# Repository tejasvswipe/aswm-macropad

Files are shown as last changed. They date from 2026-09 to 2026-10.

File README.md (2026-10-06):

# hackpad 
## show rather then tell 
### used xiao  rp2040 , 16 keys ,roatary incoder ,  and some stuff from my  side
hackpad16_backhackpad16_schematic_previewhackpad16_pcb_preview
hackpad16_front
hackpad16_back

[hackpadSCH.pdf](https://github.com/user-attachments/files/33123543/hackpadSCH.pdf)




| Component | What it do | GPIO | Receipts |
| :--- | :--- | :---: | :--- |
| Display Mux | SDA / SCL | `GPIO8` / `GPIO9` | pull-ups are your friends! |
| Neon Lighting | WS2812B Data | `GPIO4` | requires 5V logic shifts |
| The Dial | Encoder A / B / SW | `GPIO5` / `GPIO6` / `GPIO7` | uses quadrature ISR |
| Top Keys | SW1 / SW2 | `GPIO1` / `GPIO2` | crisped debounced |
| Mid Keys | SW3 / SW4 / SW7 | `GPIO42` / `GPIO41` / `GPIO40` | crisped debounced v2 |

| Bot Keys | SW6 / SW8 / SW9 | `GPIO39` / `GPIO38` / `GPIO21` | swap these keys if they do dumb things |
rt tracking your Spotify streams?

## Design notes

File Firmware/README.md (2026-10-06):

# Hackpad firmware

This is CircuitPython firmware for the **actual PCB in this repository**: a Seeed XIAO RP2040, 4×4 diode matrix, and EC11 encoder.

## Install

1. Install CircuitPython for **Seeed XIAO RP2040**.
2. Copy `boot.py` and `code.py` to the board's `CIRCUITPY` drive.
3. Copy the `adafruit_hid` library folder from the CircuitPython bundle to `CIRCUITPY/lib/`.
4. Reconnect USB. The board now appears as a keyboard plus media-control device.

## Keymap

| Key | Action |
|---|---|
| SW1 | Ctrl+C |
| SW2 | Ctrl+V |
| SW3 | Chrome next tab, Ctrl+Tab |
| SW4 | Chrome previous tab, Ctrl+Shift+Tab |
| SW5 | Chrome new tab, Ctrl+T |
| SW6 | Close tab, Ctrl+W |
| SW7 | Focus address bar, Ctrl+L |
| SW8…SW16 | Win+1…Win+9 |
| Encoder clockwise/counter-clockwise | Volume up/down |
| Encoder press | Play/pause media, including Spotify |

If the encoder direction is backwards, swap `ENC_A` and `ENC_B` in `code.py`.

## Important hardware note

The committed PCB does **not** contain the OLED displays, I²C mux, ESP32-S3, or RGB LEDs described in the README text. It is a 4×4 matrix wired to every usable XIAO RP2040 GPIO. Therefore this firmware cannot display the current time on the shipped PCB without a hardware revision that adds an OLED and frees/reroutes I²C pins.

`host/companion.py` is included as an optional time sender for a future display-equipped revision; it is not needed for the keys or encoder.

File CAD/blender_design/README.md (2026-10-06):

# Hackpad 16 — Blender case redesign

A redesigned, two-piece sandwich enclosure for the supplied 100 × 100 mm Hackpad 16 PCB. The case follows the Hackpad guide dimensions and keeps the existing board’s actual asymmetric mounting-hole locations.

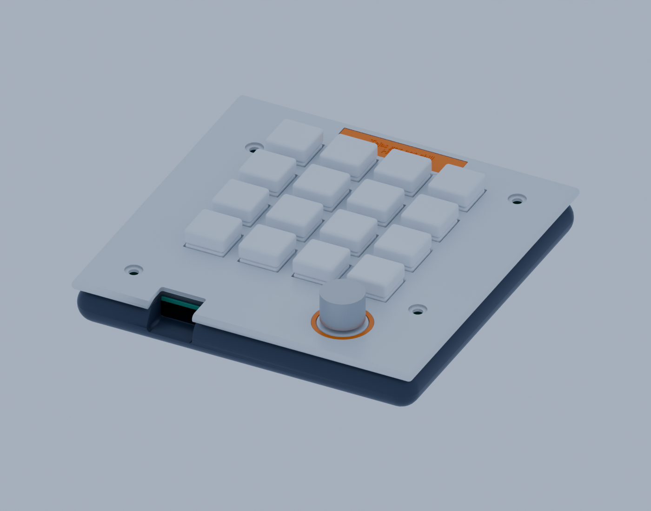
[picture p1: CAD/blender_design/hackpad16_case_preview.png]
Hackpad 16 case preview


## Guide dimensions used

- PCB cavity: 100.4 × 100.4 mm, giving 0.2 mm clearance on each side
- Outer case: 120 × 120 mm, giving a 10 mm border around the PCB
- Lower tray: 3 mm floor and 10 mm side wall
- Top switch plate: 3 mm thick
- Switches: 4 × 4 grid at 19.05 mm pitch, with 14.4 mm plate openings

The case also has an edge opening for USB-C, four PCB-matched standoffs and plate screw holes, a 7.4 mm EC11 bushing opening, a separate accent ring, and an underside hatch for access to the XIAO BOOT/RESET buttons. The badge reads “Tejas got not chill” over “Hackpad.”

The visual encoder knob is narrower than the bezel opening and stands 1.5 mm above the plate at its lower edge, leaving room for the knob to move down when pressed. The electrical click is provided by the EC11 encoder’s integrated push switch on the PCB. The real encoder and selected knob still need a physical press-fit check.

## Files

- hackpad16_case.blend — editable Blender scene. Printable case parts have numbered names; objects labelled PROXY ONLY are visual placeholders and are not printing parts.
- lower_tray.stl — lower case, including PCB standoffs and service opening
- switch_plate.stl — top plate and switch/encoder openings
- service_hatch.stl — removable access cover
- encoder_bezel.stl — optional accent ring with extra clearance around a pressable knob
- hackpad16_badge.stl — separate Tejas got not chill / Hackpad badge
- hackpad16_case_preview.png — assembled render
- build_case.py — Blender script used to generate the model and STLs

The STL files are each positioned on Z=0 for easier slicing. Print the lower tray with its floor on the bed and the plate flat. A sensible first pass is 0.2 mm layers, 3–4 walls, and 20–30% infill.

## Assembly and fit

The board pattern is intentionally asymmetric, so use this exact PCB. Use four M3 screws through the plate and PCB into the tray’s 2.7 mm pilot holes; confirm screw length against your print and board stack. The service hatch uses four M2 self-tapping screws.

This is a CAD redesign and has not been physically test-fitted. Before printing everything, test one switch opening and check the exact switches, encoder nut/bushing, USB-C plug, board standoff alignment, and XIAO service-hatch access against your hardware and printer. Dimensions may need adjustment for printer shrinkage and component tolerances.

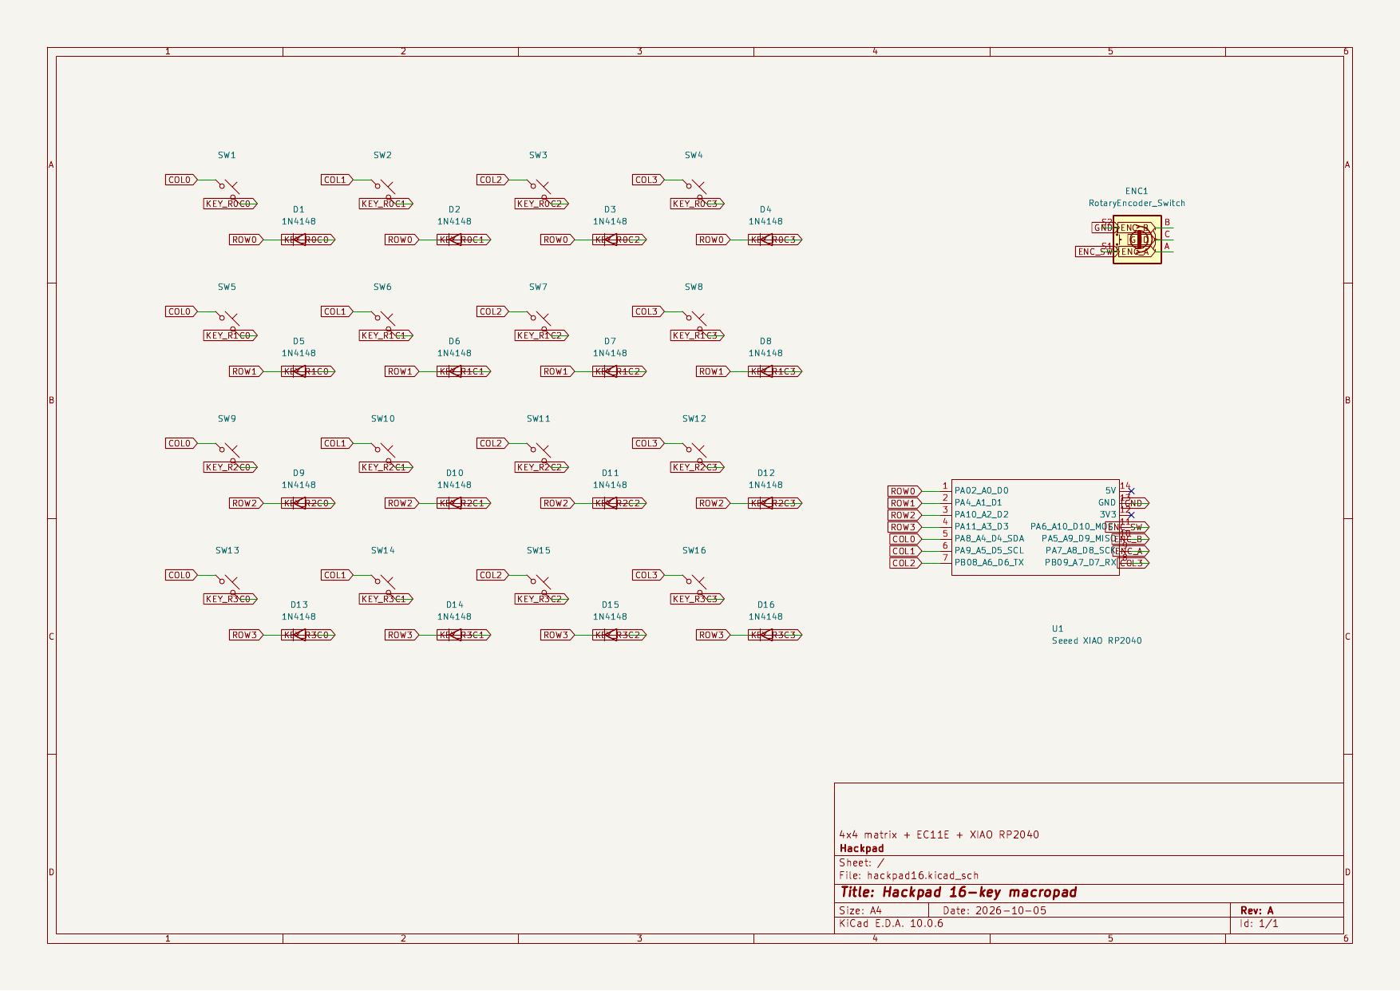
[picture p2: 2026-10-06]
PCB/previews/hackpad16_schematic_preview.png

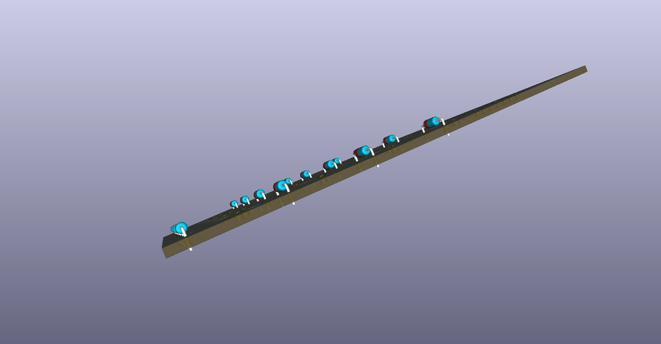
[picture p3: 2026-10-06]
PCB/hackpad16.png

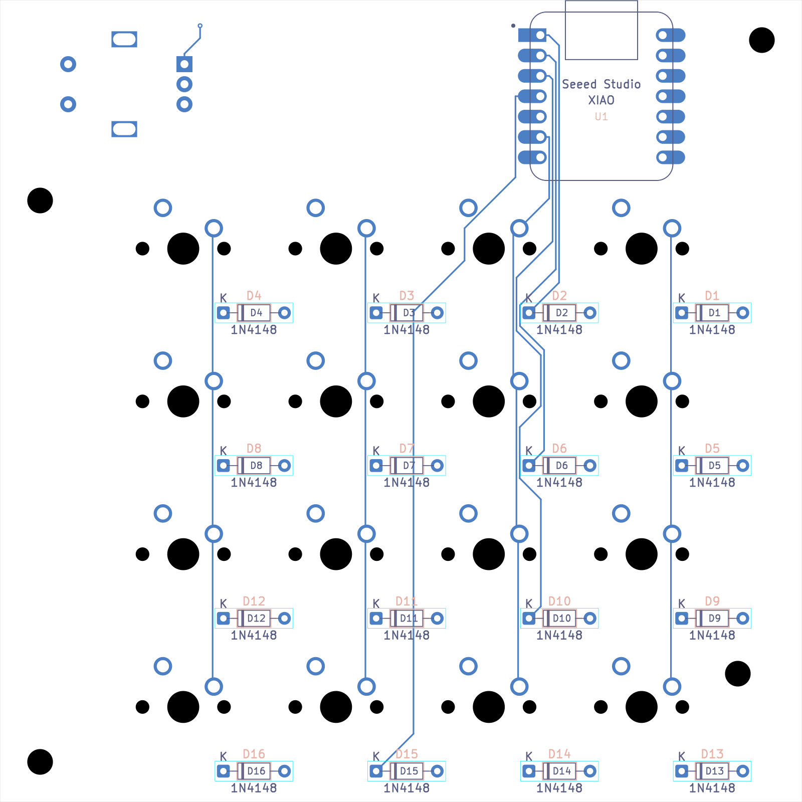
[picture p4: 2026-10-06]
PCB/previews/hackpad16_back.png

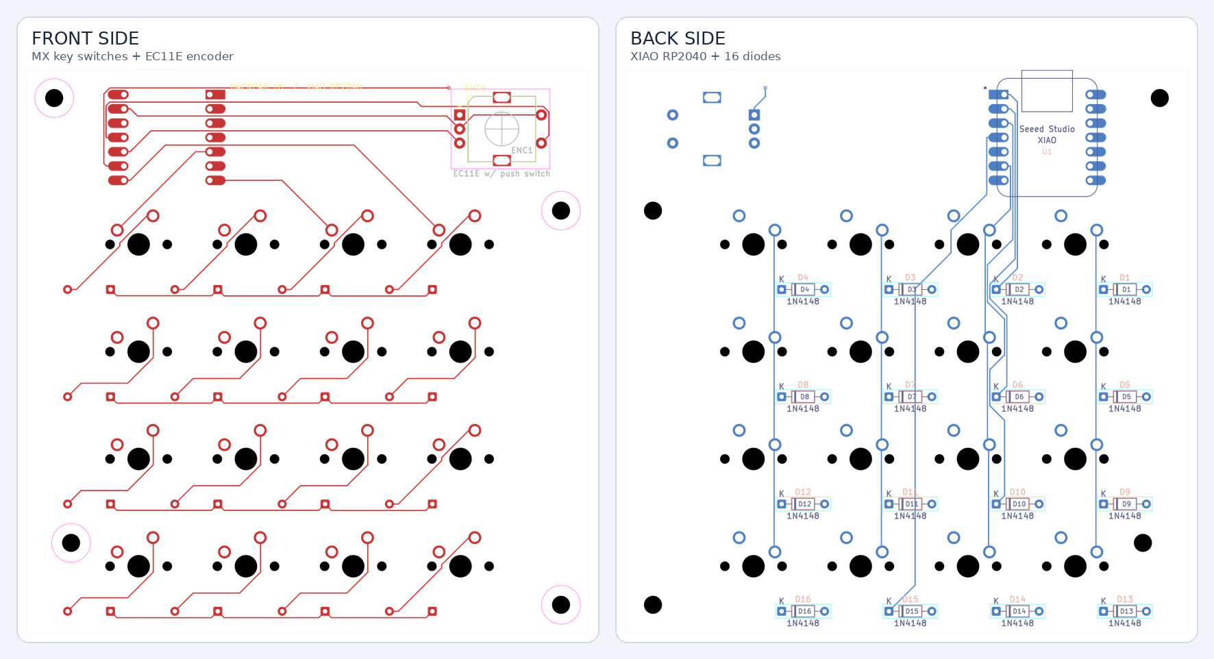
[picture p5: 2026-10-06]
PCB/previews/hackpad16_pcb_preview.png

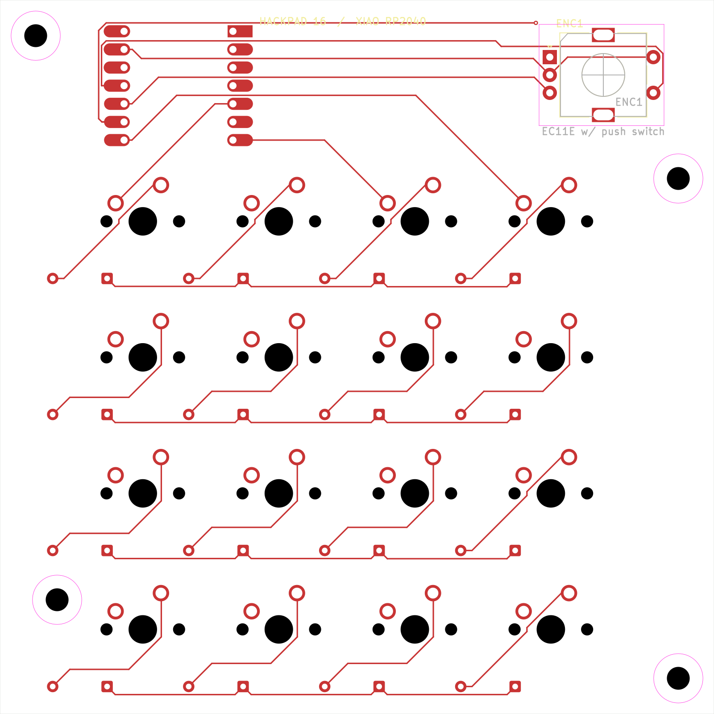
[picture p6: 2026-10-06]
PCB/previews/hackpad16_front.png

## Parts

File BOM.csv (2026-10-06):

Quantity | Part | Specification / notes | Reference link
1 | XIAO RP2040 | Seeed XIAO RP2040 module | https://wiki.seeedstudio.com/XIAO-RP2040/
16 | Mechanical key switch | MX-compatible 1U; select preferred switch | https://www.digikey.in/en/products/result?keywords=MX%20keyboard%20switch
16 | Signal diode | 1N4148 through-hole | https://www.onsemi.com/pdf/datasheet/1n4148-d.pdf
1 | Rotary encoder with push switch | EC11E-compatible; verify shaft and bushing variant | https://www.digikey.in/en/products/result?keywords=EC11E%20encoder
16 | Keycap | MX-compatible 1U | https://www.digikey.in/en/products/result?keywords=1U%20MX%20keycap
4 | Case fastener | M3 x 10 mm for plate/PCB/standoff stack; confirm fit | https://www.digikey.in/en/products/result?keywords=M3%2010mm%20screw
4 | Hatch fastener | M2 x 6 mm self-tapping screw | https://www.digikey.in/en/products/result?keywords=M2%206mm%20self%20tapping%20screw
1 set | Printed case | Lower tray and switch plate; hatch; bezel and badge optional | CAD/blender_design/README.md

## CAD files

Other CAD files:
CAD/blender_design/hackpad16_case.blend

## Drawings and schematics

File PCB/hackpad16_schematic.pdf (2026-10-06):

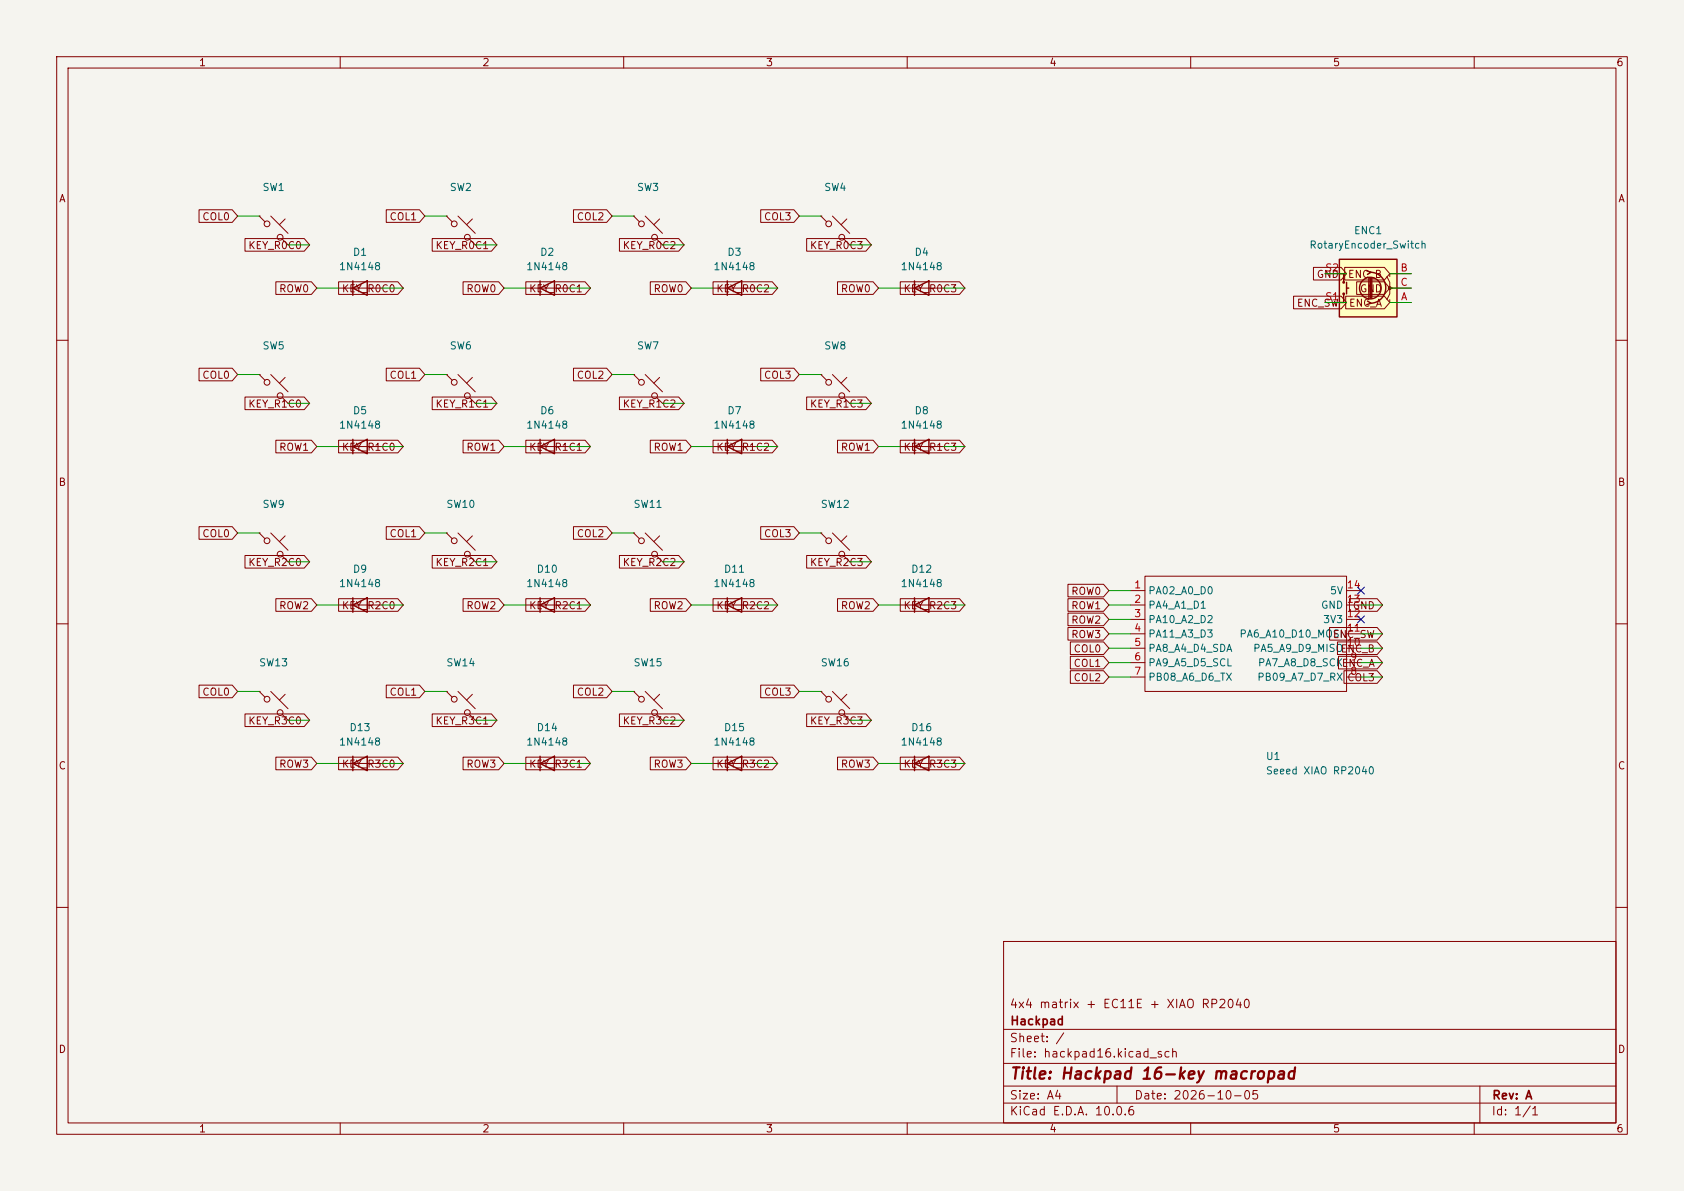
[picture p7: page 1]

Size: A4 | Rev: A
KiCad E.D.A. 10.0.6 | Id: 1/1

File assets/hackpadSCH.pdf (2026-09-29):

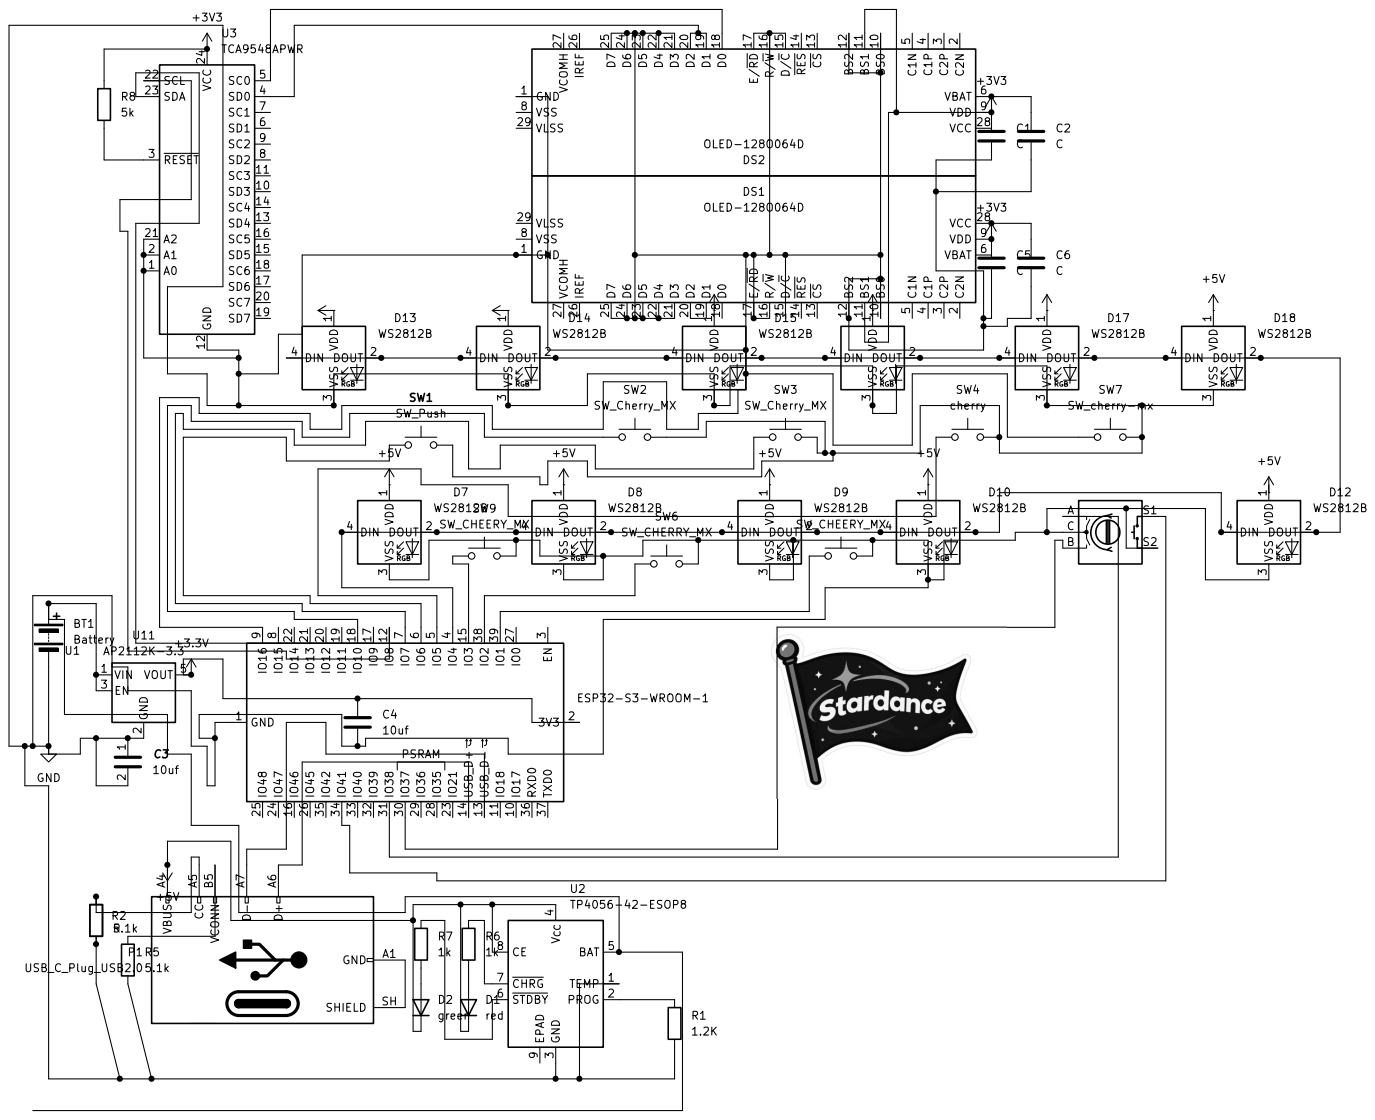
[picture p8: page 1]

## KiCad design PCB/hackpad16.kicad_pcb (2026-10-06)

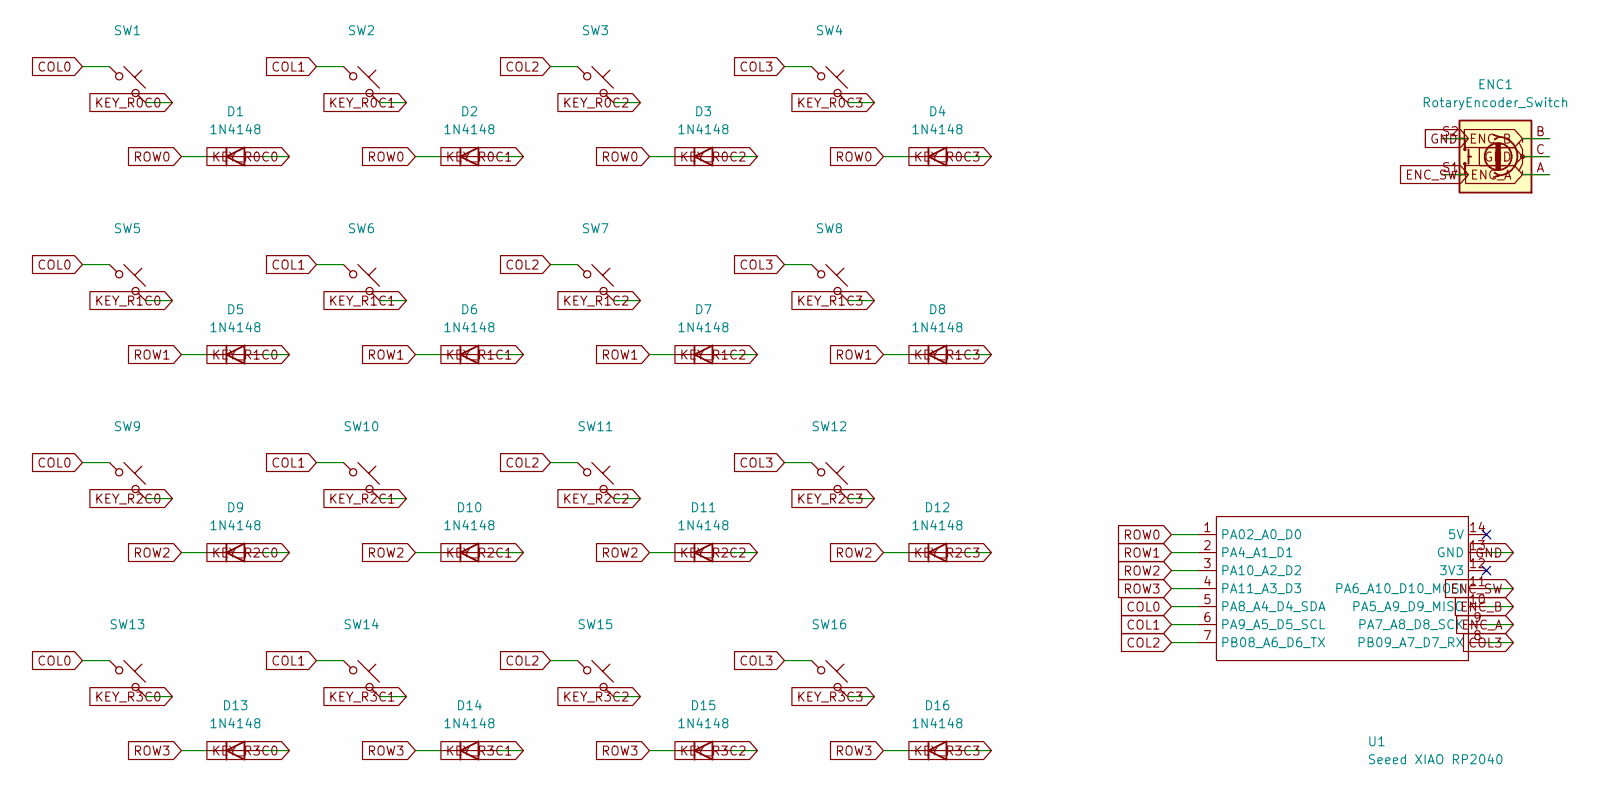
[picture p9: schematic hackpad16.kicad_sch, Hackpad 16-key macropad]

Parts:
D1, D2, D3, D4, D5, D6, D7, D8, D9, D10, D11, D12, D13, D14, D15, D16: 1N4148; D_DO-35_SOD27_P7.62mm_Horizontal
ENC1: RotaryEncoder_Switch; RotaryEncoder_Alps_EC11E-Switch_Vertical_H20mm
SW1, SW2, SW3, SW4, SW5, SW6, SW7, SW8, SW9, SW10, SW11, SW12, SW13, SW14, SW15, SW16: SW_Push_45deg; MX-Solderable-1U
U1: Seeed XIAO RP2040; XIAO-Generic-Hybrid-14P-2.54-21X17.8MM

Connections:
COL0: SW1.1, SW5.1, SW9.1, SW13.1, U1.5 (PA8_A4_D4_SDA)
COL1: SW2.1, SW6.1, SW10.1, SW14.1, U1.6 (PA9_A5_D5_SCL)
COL2: SW3.1, SW7.1, SW11.1, SW15.1, U1.7 (PB08_A6_D6_TX)
COL3: SW4.1, SW8.1, SW12.1, SW16.1, U1.8 (PB09_A7_D7_RX)
ENC_A: ENC1.A, U1.9 (PA7_A8_D8_SCK)
ENC_B: ENC1.B, U1.10 (PA5_A9_D9_MISO)
ENC_SW: ENC1.S1, U1.11 (PA6_A10_D10_MOSI)
GND: ENC1.C, ENC1.S2, U1.13 (GND)
KEY_R0C0: D1.2 (A), SW1.2
KEY_R0C1: D2.2 (A), SW2.2
KEY_R0C2: D3.2 (A), SW3.2
KEY_R0C3: D4.2 (A), SW4.2
KEY_R1C0: D5.2 (A), SW5.2
KEY_R1C1: D6.2 (A), SW6.2
KEY_R1C2: D7.2 (A), SW7.2
KEY_R1C3: D8.2 (A), SW8.2
KEY_R2C0: D9.2 (A), SW9.2
KEY_R2C1: D10.2 (A), SW10.2
KEY_R2C2: D11.2 (A), SW11.2
KEY_R2C3: D12.2 (A), SW12.2
KEY_R3C0: D13.2 (A), SW13.2
KEY_R3C1: D14.2 (A), SW14.2
KEY_R3C2: D15.2 (A), SW15.2
KEY_R3C3: D16.2 (A), SW16.2
ROW0: D1.1 (K), D2.1 (K), D3.1 (K), D4.1 (K), U1.1 (PA02_A0_D0)
ROW1: D5.1 (K), D6.1 (K), D7.1 (K), D8.1 (K), U1.2 (PA4_A1_D1)
ROW2: D9.1 (K), D10.1 (K), D11.1 (K), D12.1 (K), U1.3 (PA10_A2_D2)
ROW3: D13.1 (K), D14.1 (K), D15.1 (K), D16.1 (K), U1.4 (PA11_A3_D3)

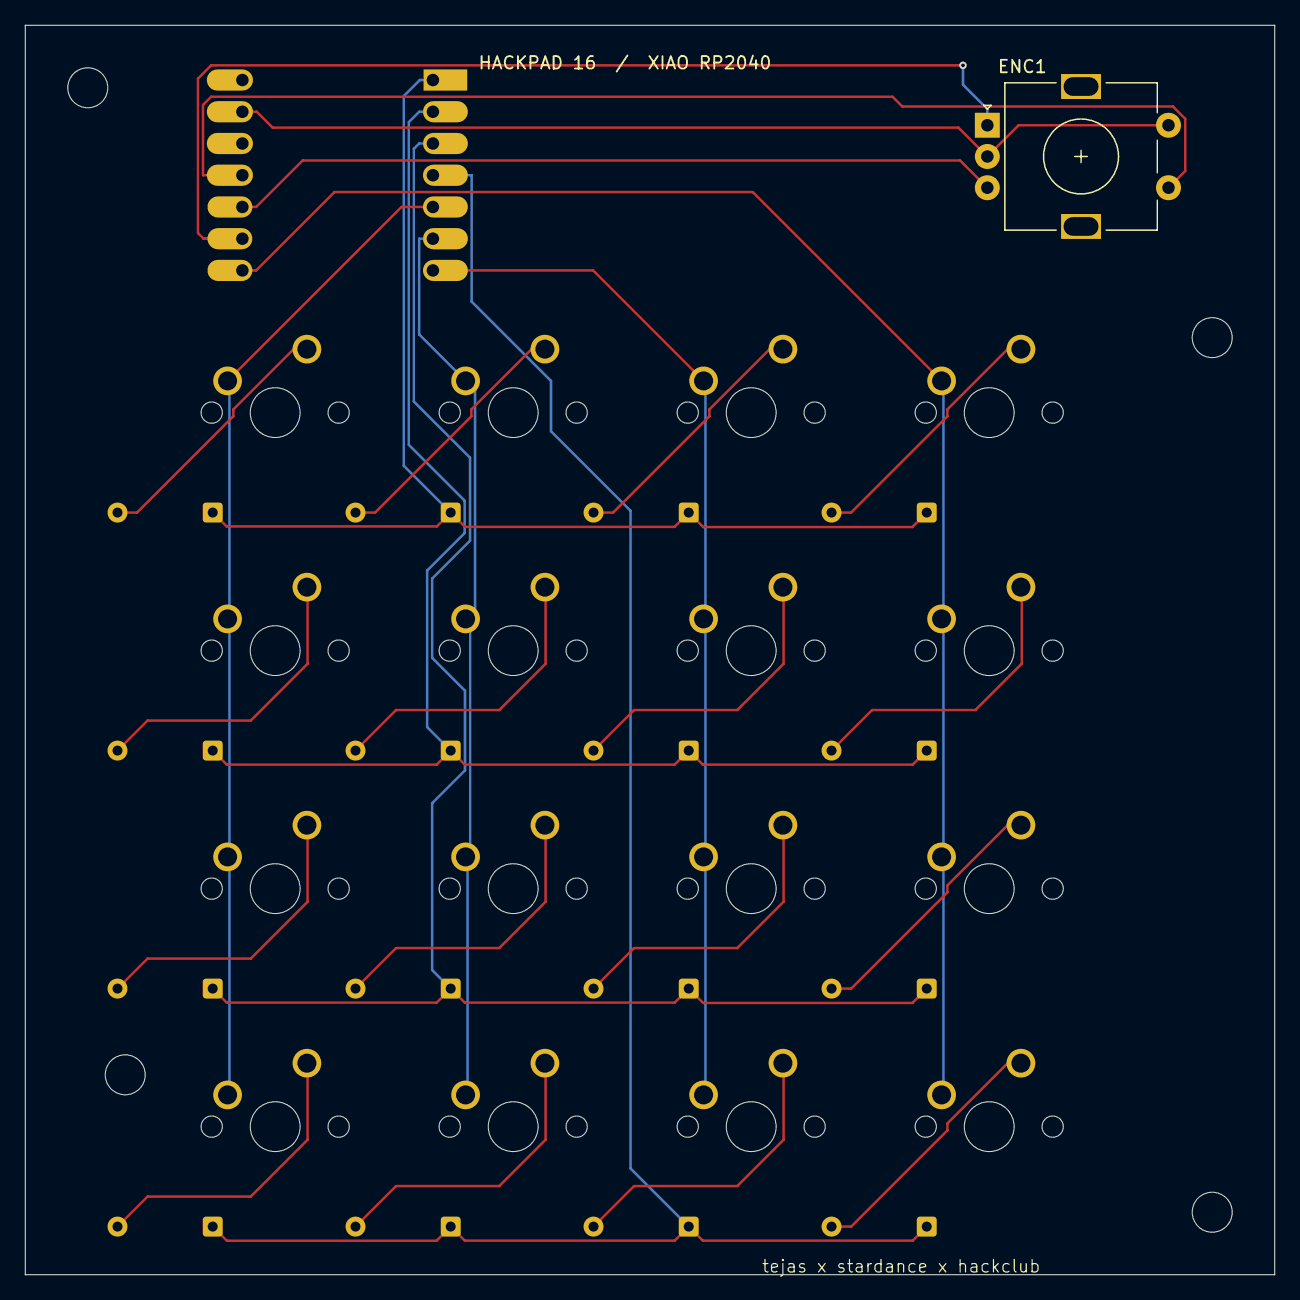
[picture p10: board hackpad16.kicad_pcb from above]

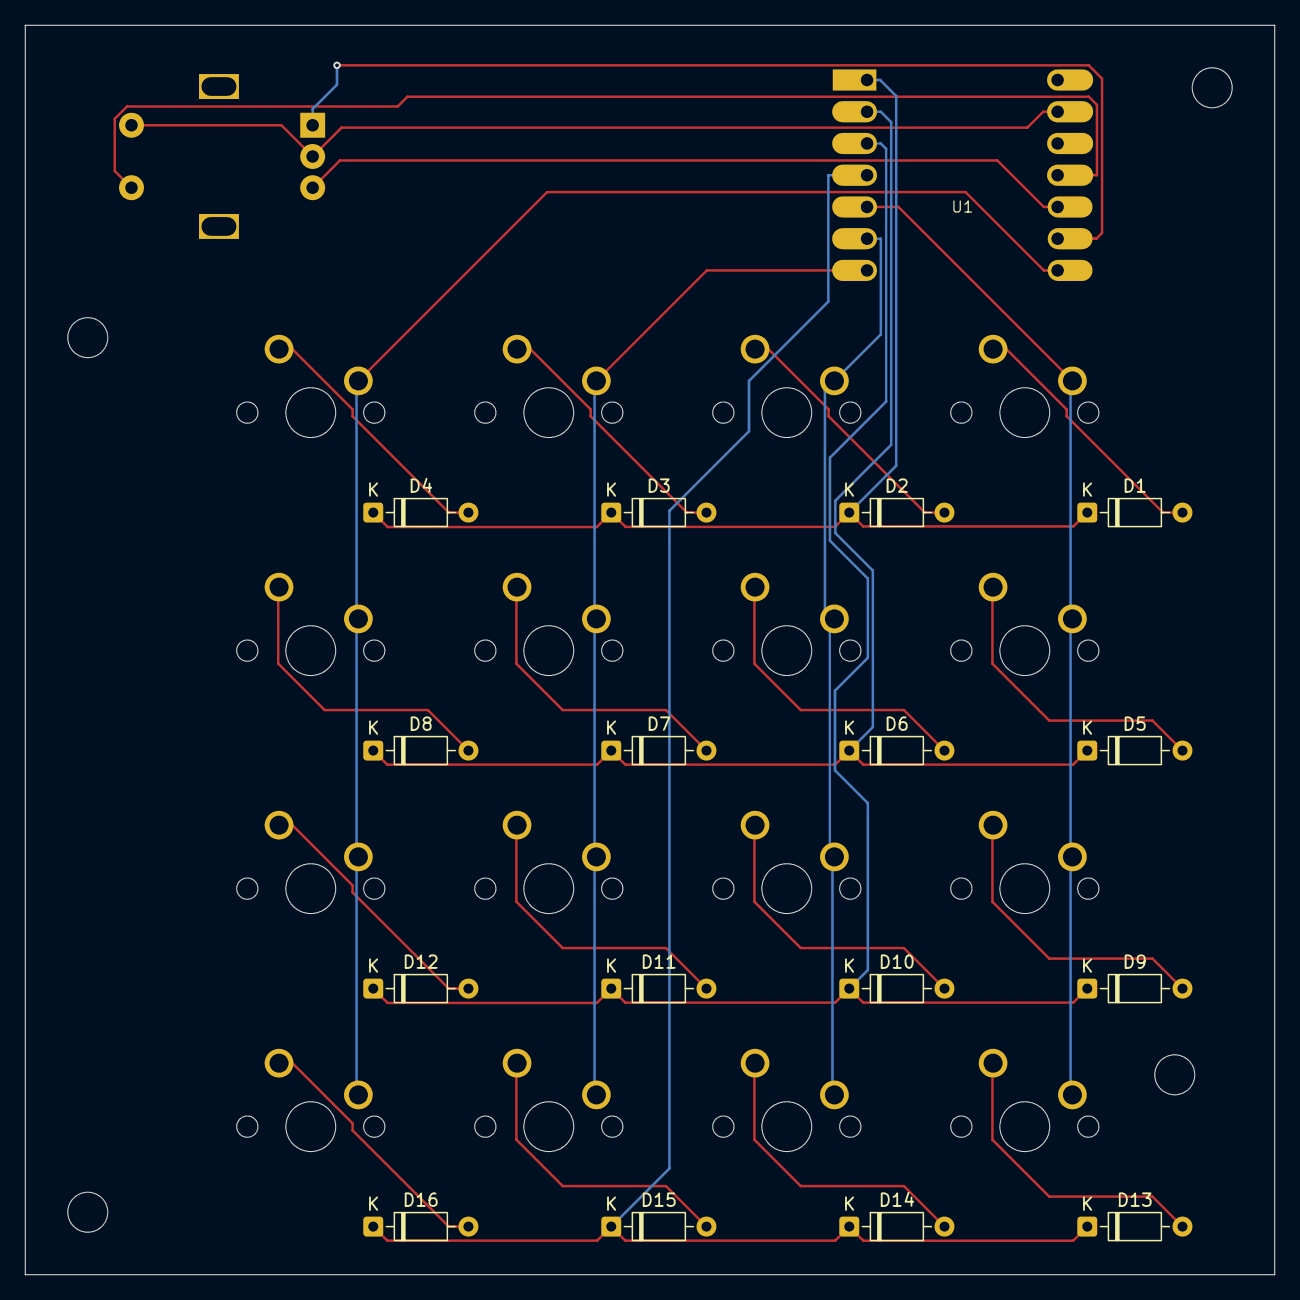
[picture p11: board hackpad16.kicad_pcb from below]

Board: 2 copper layers, 100.0 x 100.0 mm, 38 parts (17 on the bottom side), 28 nets.

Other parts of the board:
H1, H2, H3, H4: M3 Mounting Hole; MountingHole_3.2mm_M3

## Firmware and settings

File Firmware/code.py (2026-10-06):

import time
import board
import digitalio
import usb_hid
from adafruit_hid.keyboard import Keyboard
from adafruit_hid.keycode import Keycode
from adafruit_hid.consumer_control import ConsumerControl
from adafruit_hid.consumer_control_code import ConsumerControlCode

# KiCad schematic pinout: ROW0..3 = D0..D3, COL0..3 = D4..D7.
ROWS = (board.D0, board.D1, board.D2, board.D3)
COLS = (board.D4, board.D5, board.D6, board.D7)
ENC_A, ENC_B, ENC_SW = board.D8, board.D9, board.D10

keyboard = Keyboard(usb_hid.devices)
consumer = ConsumerControl(usb_hid.devices)

rows = []
for pin in ROWS:
    io = digitalio.DigitalInOut(pin)
    io.direction = digitalio.Direction.INPUT
    io.pull = digitalio.Pull.UP
    rows.append(io)

cols = []
for pin in COLS:
    io = digitalio.DigitalInOut(pin)
    io.direction = digitalio.Direction.OUTPUT
    io.value = True
    cols.append(io)

enc_a = digitalio.DigitalInOut(ENC_A)
enc_a.direction = digitalio.Direction.INPUT
enc_a.pull = digitalio.Pull.UP
enc_b = digitalio.DigitalInOut(ENC_B)
enc_b.direction = digitalio.Direction.INPUT
enc_b.pull = digitalio.Pull.UP
enc_sw = digitalio.DigitalInOut(ENC_SW)
enc_sw.direction = digitalio.Direction.INPUT
enc_sw.pull = digitalio.Pull.UP

# SW1..SW16: copy, paste, Chrome tab controls, then Windows workspaces.
# The matrix is scanned row-major: SW1 = row 0/col 0.
KEYMAP = {
    0: (Keycode.CONTROL, Keycode.C),
    1: (Keycode.CONTROL, Keycode.V),
    2: (Keycode.CONTROL, Keycode.TAB),
    3: (Keycode.CONTROL, Keycode.SHIFT, Keycode.TAB),
    4: (Keycode.CONTROL, Keycode.T),
    5: (Keycode.CONTROL, Keycode.W),
    6: (Keycode.CONTROL, Keycode.L),
    7: (Keycode.GUI, Keycode.ONE),
    8: (Keycode.GUI, Keycode.TWO),
    9: (Keycode.GUI, Keycode.THREE),
    10: (Keycode.GUI, Keycode.FOUR),
    11: (Keycode.GUI, Keycode.FIVE),
    12: (Keycode.GUI, Keycode.SIX),
    13: (Keycode.GUI, Keycode.SEVEN),
    14: (Keycode.GUI, Keycode.EIGHT),
    15: (Keycode.GUI, Keycode.NINE),
}

last_keys = [False] * 16
last_scan = 0
last_encoder = (enc_a.value << 1) | enc_b.value
last_encoder_step = 0
last_encoder_time = 0
last_encoder_switch = True
last_switch_time = 0

# Quadrature transitions. Direction may be reversed by swapping ENC_A/ENC_B.
QUAD = {
    (0, 1): 1, (1, 3): 1, (3, 2): 1, (2, 0): 1,
    (0, 2): -1, (2, 3): -1, (3, 1): -1, (1, 0): -1,
}


def tap(combo):
    for key in combo:
        keyboard.press(key)
    for key in reversed(combo):
        keyboard.release(key)


def scan_keys(now):
    global last_scan
    if now - last_scan < 0.002:
        return
    last_scan = now
    current = [False] * 16
    for col, output in enumerate(cols):
        output.value = False
        time.sleep(0.00015)
        for row, input_pin in enumerate(rows):
            current[row * 4 + col] = not input_pin.value
        output.value = True
    for index, pressed in enumerate(current):
        if pressed and not last_keys[index]:
            tap(KEYMAP[index])
    last_keys[:] = current


def scan_encoder(now):
    global last_encoder, last_encoder_step, last_encoder_time
    state = (enc_a.value << 1) | enc_b.value
    delta = QUAD.get((last_encoder, state), 0)
    last_encoder = state
    if delta:
        last_encoder_step += delta
        if abs(last_encoder_step) >= 4 and now - last_encoder_time > 0.03:
            if last_encoder_step > 0:
                consumer.send(ConsumerControlCode.VOLUME_INCREMENT)
            else:
                consumer.send(ConsumerControlCode.VOLUME_DECREMENT)
            last_encoder_step = 0
            last_encoder_time = now


def scan_encoder_switch(now):
    global last_encoder_switch, last_switch_time
    pressed = not enc_sw.value
    if pressed and last_encoder_switch and now - last_switch_time > 0.18:
        # Works with Spotify and other media players through the OS media key.
        consumer.send(ConsumerControlCode.PLAY_PAUSE)
        last_switch_time = now
    last_encoder_switch = pressed


while True:
    now = time.monotonic()
    scan_keys(now)
    scan_encoder(now)
    scan_encoder_switch(now)
    time.sleep(0.001)

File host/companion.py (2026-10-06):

"""Optional status sender for a future display-equipped board.

The shipped PCB has no display, so this is intentionally not required for HID
operation. It sends a simple line once per second over the CircuitPython USB
serial port for a later OLED/display revision.
"""
import argparse
import datetime as dt
import time

import serial

parser = argparse.ArgumentParser()
parser.add_argument("port", help="CircuitPython USB serial port, e.g. COM7")
parser.add_argument("--baud", type=int, default=115200)
args = parser.parse_args()

with serial.Serial(args.port, args.baud, timeout=1) as device:
    while True:
        now = dt.datetime.now().astimezone().isoformat(timespec="seconds")
        device.write(f"T\t{now}\n".encode())
        time.sleep(1)

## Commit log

2026-09-29 bill of material done , sirrrr
    [BOM.csv]
2026-09-29 images added
    [hackpad-design.blend]
2026-10-06 bill of material obv
    [BOM.csv]
2026-10-06 remove unused files and code: delete hackpad design, configuration, LED, state, UI, and main source files
    [hackpad-design.blend]
2026-10-06 add redesigned Blender case files and remove obsolete components
    [BOM.csv, hackpad16_case.blend]
2026-10-06 add lock file for hackpad schematic
2026-10-06 add fp-lib-table for KiCad library components
2026-10-06 add hackpad16 schematic PDF for 16-key macropad design
2026-10-06 its pcbbbbbbb
    [hackpad16.kicad_pcb]
2026-10-06 add hackpad16.kicad_prl file for 16-key macropad design
2026-10-06 Refactor code structure for improved readability and maintainability
    [hackpad16.kicad_sch]
2026-10-06 add XIAO_RP2040.kicad_sym file for Seeeduino XIAO module
2026-10-06 Add new footprints and symbol files for Diode and Mounting Hole components
2026-10-06 Add preview images for hackpad16 PCB design
    - Added hackpad16_back.png for the back view of the PCB.
    - Added hackpad16_front.png for the front view of the PCB.
2026-10-06 Add DRC and ERC reports for hackpad16 PCB design
2026-10-06 Add PCB previews for hackpad16: schematic and layout images
2026-10-06 Ignore KiCad history
2026-10-06 Revise README for hardware updates and new visuals
    Updated the README to reflect changes in hardware and features, including new images and a link to the schematic.
2026-10-13 Replace Blender CAD workflow with OpenSCAD and STL exports
2026-10-13 Add STL-derived SVG CAD preview to README gallery
